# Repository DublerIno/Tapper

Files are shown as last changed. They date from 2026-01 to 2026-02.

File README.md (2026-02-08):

# Tapper
Simple BPM counter and metronome on custom board, replacing apps filled with Ads. 
STM32G030F6P6 TSSOP20 as a brain. MX Cherry switch for satisfying click. OLED for visuals. 

## GOAL
This simple project may seem like reinventing the wheel, but my main goal is to learn:
- STM32 Programming pipeline
- Custom PCB design for embedded systems
- Microsoldering 

### STM32G030F6P6 Dev Board
Currently, I am working on my custom development board to test the following features:
- STlink connection
- USBC connection with CH340E for UART
- Battery charging circuit for LiPo with MCP73831
- OLED test circuit
- STM32 pinouts

### Current status
- PCB done
- Soldering done
- Circuit testing successful
- Now programming..
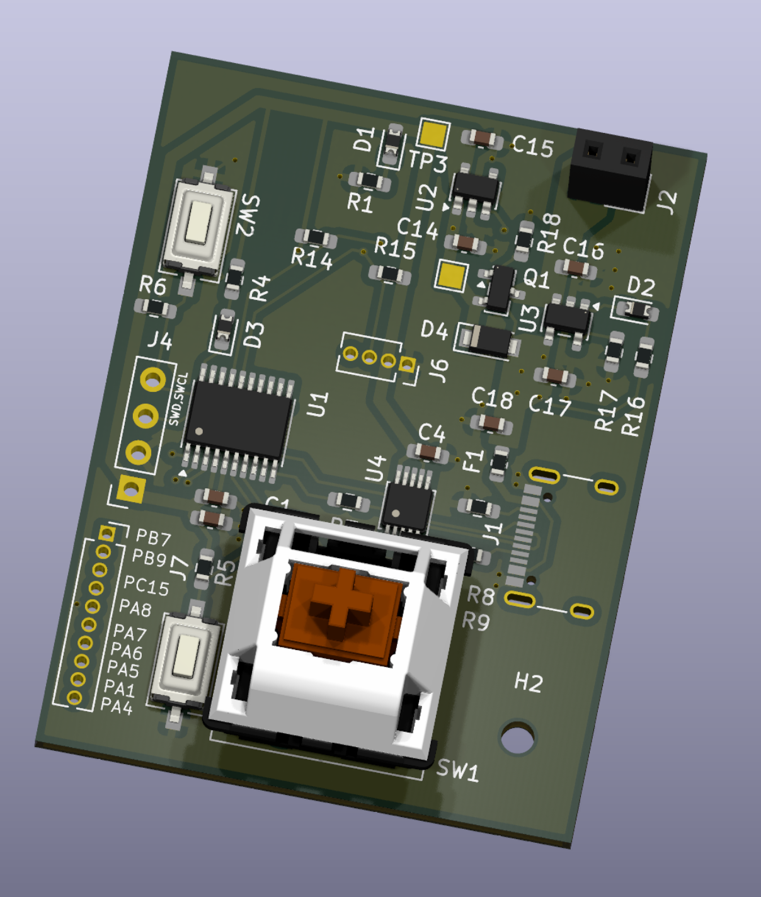
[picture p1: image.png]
Tapper Dev board v1


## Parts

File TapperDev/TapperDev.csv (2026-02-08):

Reference | Qty | Value | DNP | Exclude from BOM | Exclude from Board | Footprint | Datasheet
C1 | 1 | 10u |  |  |  | Capacitor_SMD:C_0603_1608Metric_Pad1.08x0.95mm_HandSolder | ~
C2,C4,C18 | 3 | 100n |  |  |  | Capacitor_SMD:C_0603_1608Metric_Pad1.08x0.95mm_HandSolder | ~
C3,C5 | 2 | ?? | DNP |  | Vyloučit z desky | Capacitor_SMD:C_0603_1608Metric_Pad1.08x0.95mm_HandSolder | ~
C6 | 1 | 1uF/16v |  |  |  | Capacitor_SMD:C_0603_1608Metric_Pad1.08x0.95mm_HandSolder | ~
C7 | 1 | 1uF/16V |  |  |  | Capacitor_SMD:C_0603_1608Metric_Pad1.08x0.95mm_HandSolder | ~
C8,C10 | 2 | 4.7uF |  |  |  | Capacitor_SMD:C_0603_1608Metric_Pad1.08x0.95mm_HandSolder | ~
C9 | 1 | 0.1uF |  |  |  | Capacitor_SMD:C_0603_1608Metric_Pad1.08x0.95mm_HandSolder | ~
C11,C16,C17 | 3 | 4.7uF/16V |  |  |  | Capacitor_SMD:C_0603_1608Metric_Pad1.08x0.95mm_HandSolder | ~
C12 | 1 | 0.1uF/16V |  |  |  | Capacitor_SMD:C_0603_1608Metric_Pad1.08x0.95mm_HandSolder | ~
C13 | 1 | 2.2uF/16V |  |  |  | Capacitor_SMD:C_0603_1608Metric_Pad1.08x0.95mm_HandSolder | ~
C14,C15 | 2 | 1uF |  |  |  | Capacitor_SMD:C_0603_1608Metric_Pad1.08x0.95mm_HandSolder | ~
D1 | 1 | LED green |  |  |  | Diode_SMD:D_0603_1608Metric_Pad1.05x0.95mm_HandSolder | ~
D2,D3 | 2 | LED red |  |  |  | Diode_SMD:D_0603_1608Metric_Pad1.05x0.95mm_HandSolder | ~
D4 | 1 | 500mA 30V |  |  |  | Diode_SMD:Nexperia_CFP3_SOD-123W | https://www.diodes.com/assets/Datasheets/ds30396.pdf
F1 | 1 | 6v 500mA |  |  |  | Diode_SMD:Nexperia_CFP3_SOD-123W | ~
J1 | 1 | USB_C_Receptacle_USB2.0_16P |  |  |  | Connector_USB:USB_C_Receptacle_XKB_U262-16XN-4BVC11 | https://www.usb.org/sites/default/files/documents/usb_type-c.zip
J2 | 1 | Conn_01x02 |  |  |  | Connector_PinSocket_2.54mm:PinSocket_1x02_P2.54mm_Vertical | ~
J3 | 1 | Conn_01x14 |  |  |  | Connector_FFC-FPC:TE_1-84952-4_1x14-1MP_P1.0mm_Horizontal | ~
J4 | 1 | Conn_01x04 |  |  |  | Connector_PinSocket_2.54mm:PinSocket_1x04_P2.54mm_Vertical | ~
J6 | 1 | Conn_01x04 |  |  |  | Connector_PinSocket_1.27mm:PinSocket_1x04_P1.27mm_Vertical | ~
J7 | 1 | Conn_01x10_Pin |  |  |  | Connector_PinSocket_1.27mm:PinSocket_1x10_P1.27mm_Vertical | ~
Q1 | 1 | PMOS ?? |  |  |  | Package_TO_SOT_SMD:SOT-23 | https://ngspice.sourceforge.io/docs/ngspice-html-manual/manual.xhtml#cha_MOSFETs
R1,R4,R7 | 3 | 1k |  |  |  | Resistor_SMD:R_0603_1608Metric_Pad0.98x0.95mm_HandSolder | ~
R5,R6 | 2 | 10k |  |  |  | Resistor_SMD:R_0603_1608Metric_Pad0.98x0.95mm_HandSolder | ~
R8,R9,R14,R15,R17 | 5 | 5k1 |  |  |  | Resistor_SMD:R_0603_1608Metric_Pad0.98x0.95mm_HandSolder | ~
R12 | 1 | 4k7 |  |  |  | Resistor_SMD:R_0603_1608Metric_Pad0.98x0.95mm_HandSolder | ~
R13 | 1 | 560k |  |  |  | Resistor_SMD:R_0603_1608Metric_Pad0.98x0.95mm_HandSolder | ~
R16 | 1 | ! for 5V |  |  |  | Resistor_SMD:R_0603_1608Metric_Pad0.98x0.95mm_HandSolder | ~
R18 | 1 | 100k |  |  |  | Resistor_SMD:R_0603_1608Metric_Pad0.98x0.95mm_HandSolder | ~
SW1 | 1 | SW_Push |  |  |  | PCM_Switch_Keyboard_Cherry_MX:SW_Cherry_MX_PCB | ~
SW2,SW3 | 2 | SW_Push |  |  |  | Button_Switch_SMD:SW_Tactile_SPST_NO_Straight_CK_PTS636Sx25SMTRLFS | ~
TP1,TP2,TP3,TP4,TP5 | 5 | TestPoint |  |  |  | TestPoint:TestPoint_Pad_1.5x1.5mm | ~
U1 | 1 | STM32G030F6Px |  |  |  | Package_SO:TSSOP-20_4.4x6.5mm_P0.65mm | https://www.st.com/resource/en/datasheet/stm32g030f6.pdf
U2 | 1 | TLV75533PDBV |  |  |  | Package_TO_SOT_SMD:SOT-23-5 | http://www.ti.com/lit/ds/symlink/tlv755p.pdf
U3 | 1 | MCP73811T-420I-OT |  |  |  | Package_TO_SOT_SMD:SOT-23-5 | http://ww1.microchip.com/downloads/en/DeviceDoc/22036b.pdf
U4 | 1 | CH340E |  |  |  | Package_SO:MSOP-10_3x3mm_P0.5mm | https://www.mpja.com/download/35227cpdata.pdf
Y1 | 1 | Crystal 16Mhz 20pF | DNP |  | Vyloučit z desky | Crystal:Crystal_HC49-U_Vertical | ~

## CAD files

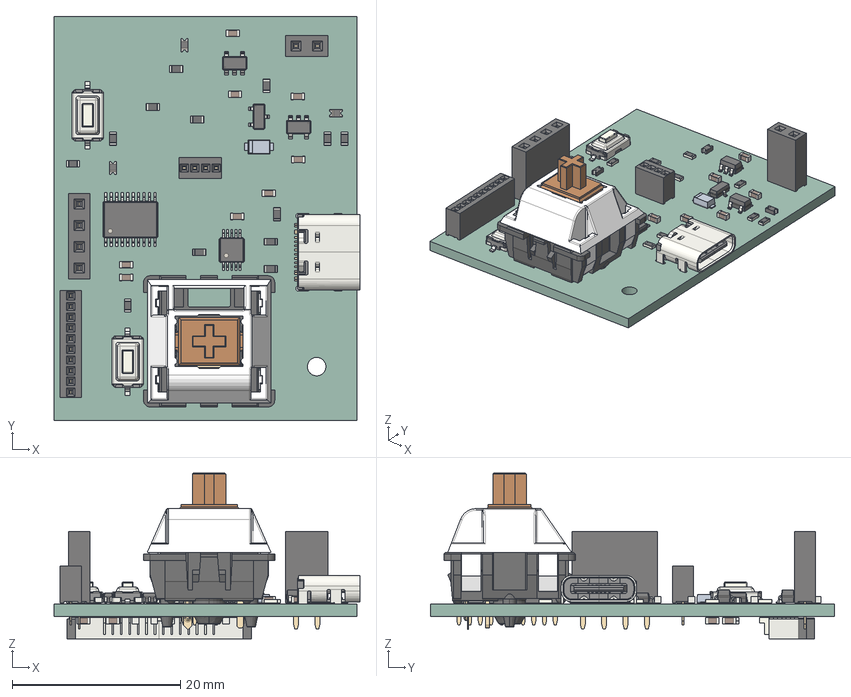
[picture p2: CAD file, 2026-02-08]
TapperDev/TapperDev.step
36.3 x 48.0 x 19.7 mm
R_0603_1608Metric x 14
SW_Cherry_MX_PCB
USB_C_Receptacle_GCT_USB4105-xx-A_16P_TopMnt_Horizontal
Fuse_0603_1608Metric
PinSocket_1x04_P2.54mm_Vertical
D_0603_1608Metric x 3
C_0603_1608Metric x 16
PinSocket_1x04_P1.27mm_Vertical
SOT-23-5 x 2
SW_Tactile_SPST_NO_Straight_CK_PTS636Sx25SMTRLFS x 2
TSSOP-20_4.4x6.5mm_P0.65mm
PinSocket_1x10_P1.27mm_Vertical
PinSocket_1x02_P2.54mm_Vertical
MSOP-10_3x3mm_P0.5mm
SOT-23
TapperDev 1.38.1
TE_1-84952-4_1x14-1MP_P1.0mm_Horizontal
TapperDev_PCB

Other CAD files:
TapperDev/TapperDev.stl
TapperDev/TapperS.f3d

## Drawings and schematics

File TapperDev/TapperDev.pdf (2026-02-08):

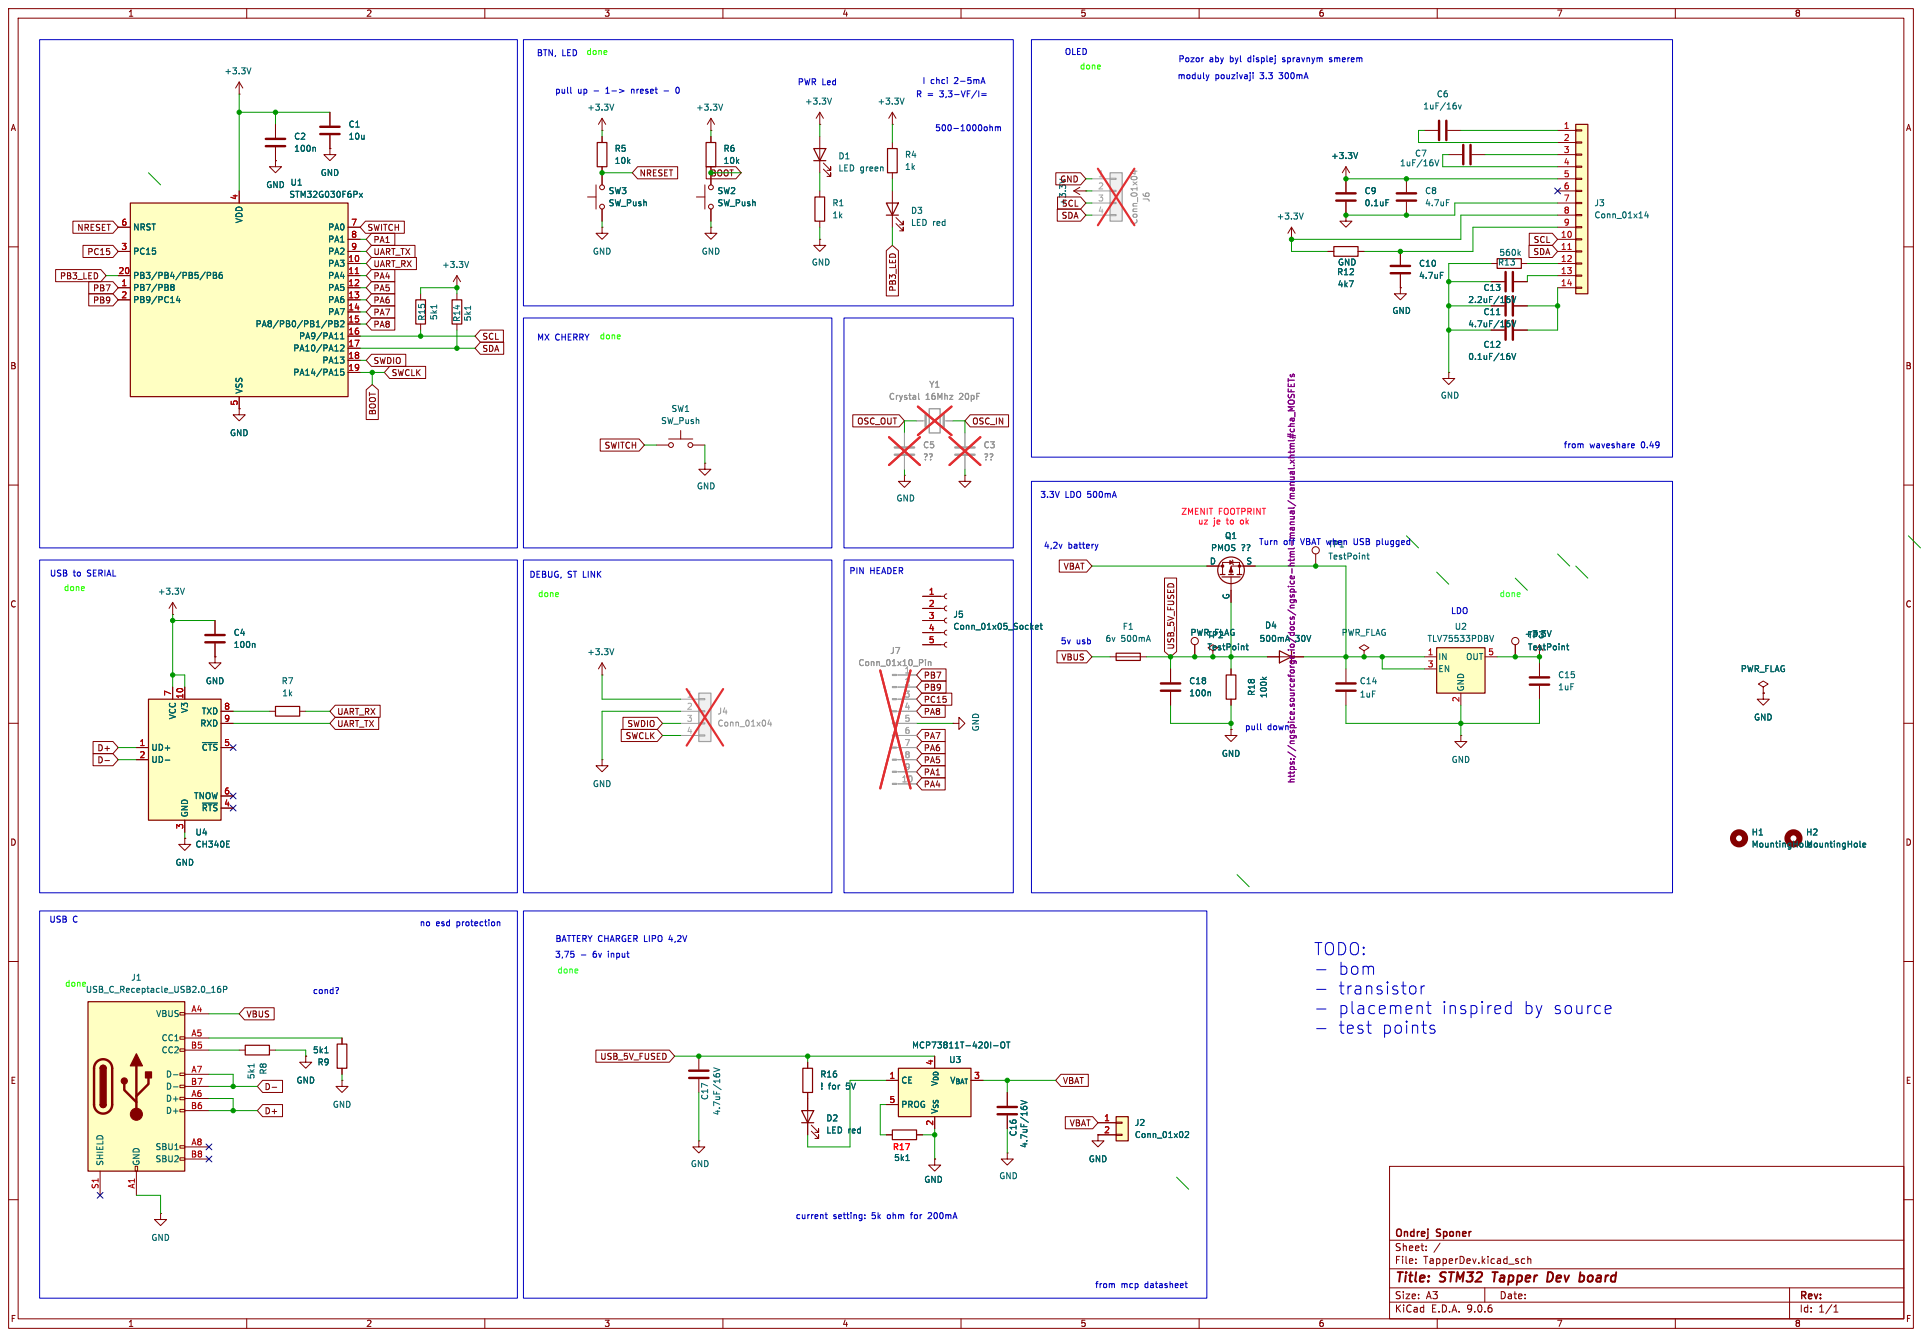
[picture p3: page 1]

Pozor aby byl displej spravnym smerem

done DEBUG, ST LINK
PIN HEADER MX CHERRY

from waveshare 0.49 Turn off VBAT when USB plugged BATTERY CHARGER LIPO 4,2V

3 TXD 8 RXD 9 ~{CTS}5 TNOW 6 ~{RTS}4 GND

3 TXD 8 RXD 9 ~{CTS}5 TNOW 6 ~{RTS}4 U4 CH340E

File: TapperDev.kicad_sch Sheet: / Ondrej Sponer

Id: 1/1 Title: STM32 Tapper Dev board

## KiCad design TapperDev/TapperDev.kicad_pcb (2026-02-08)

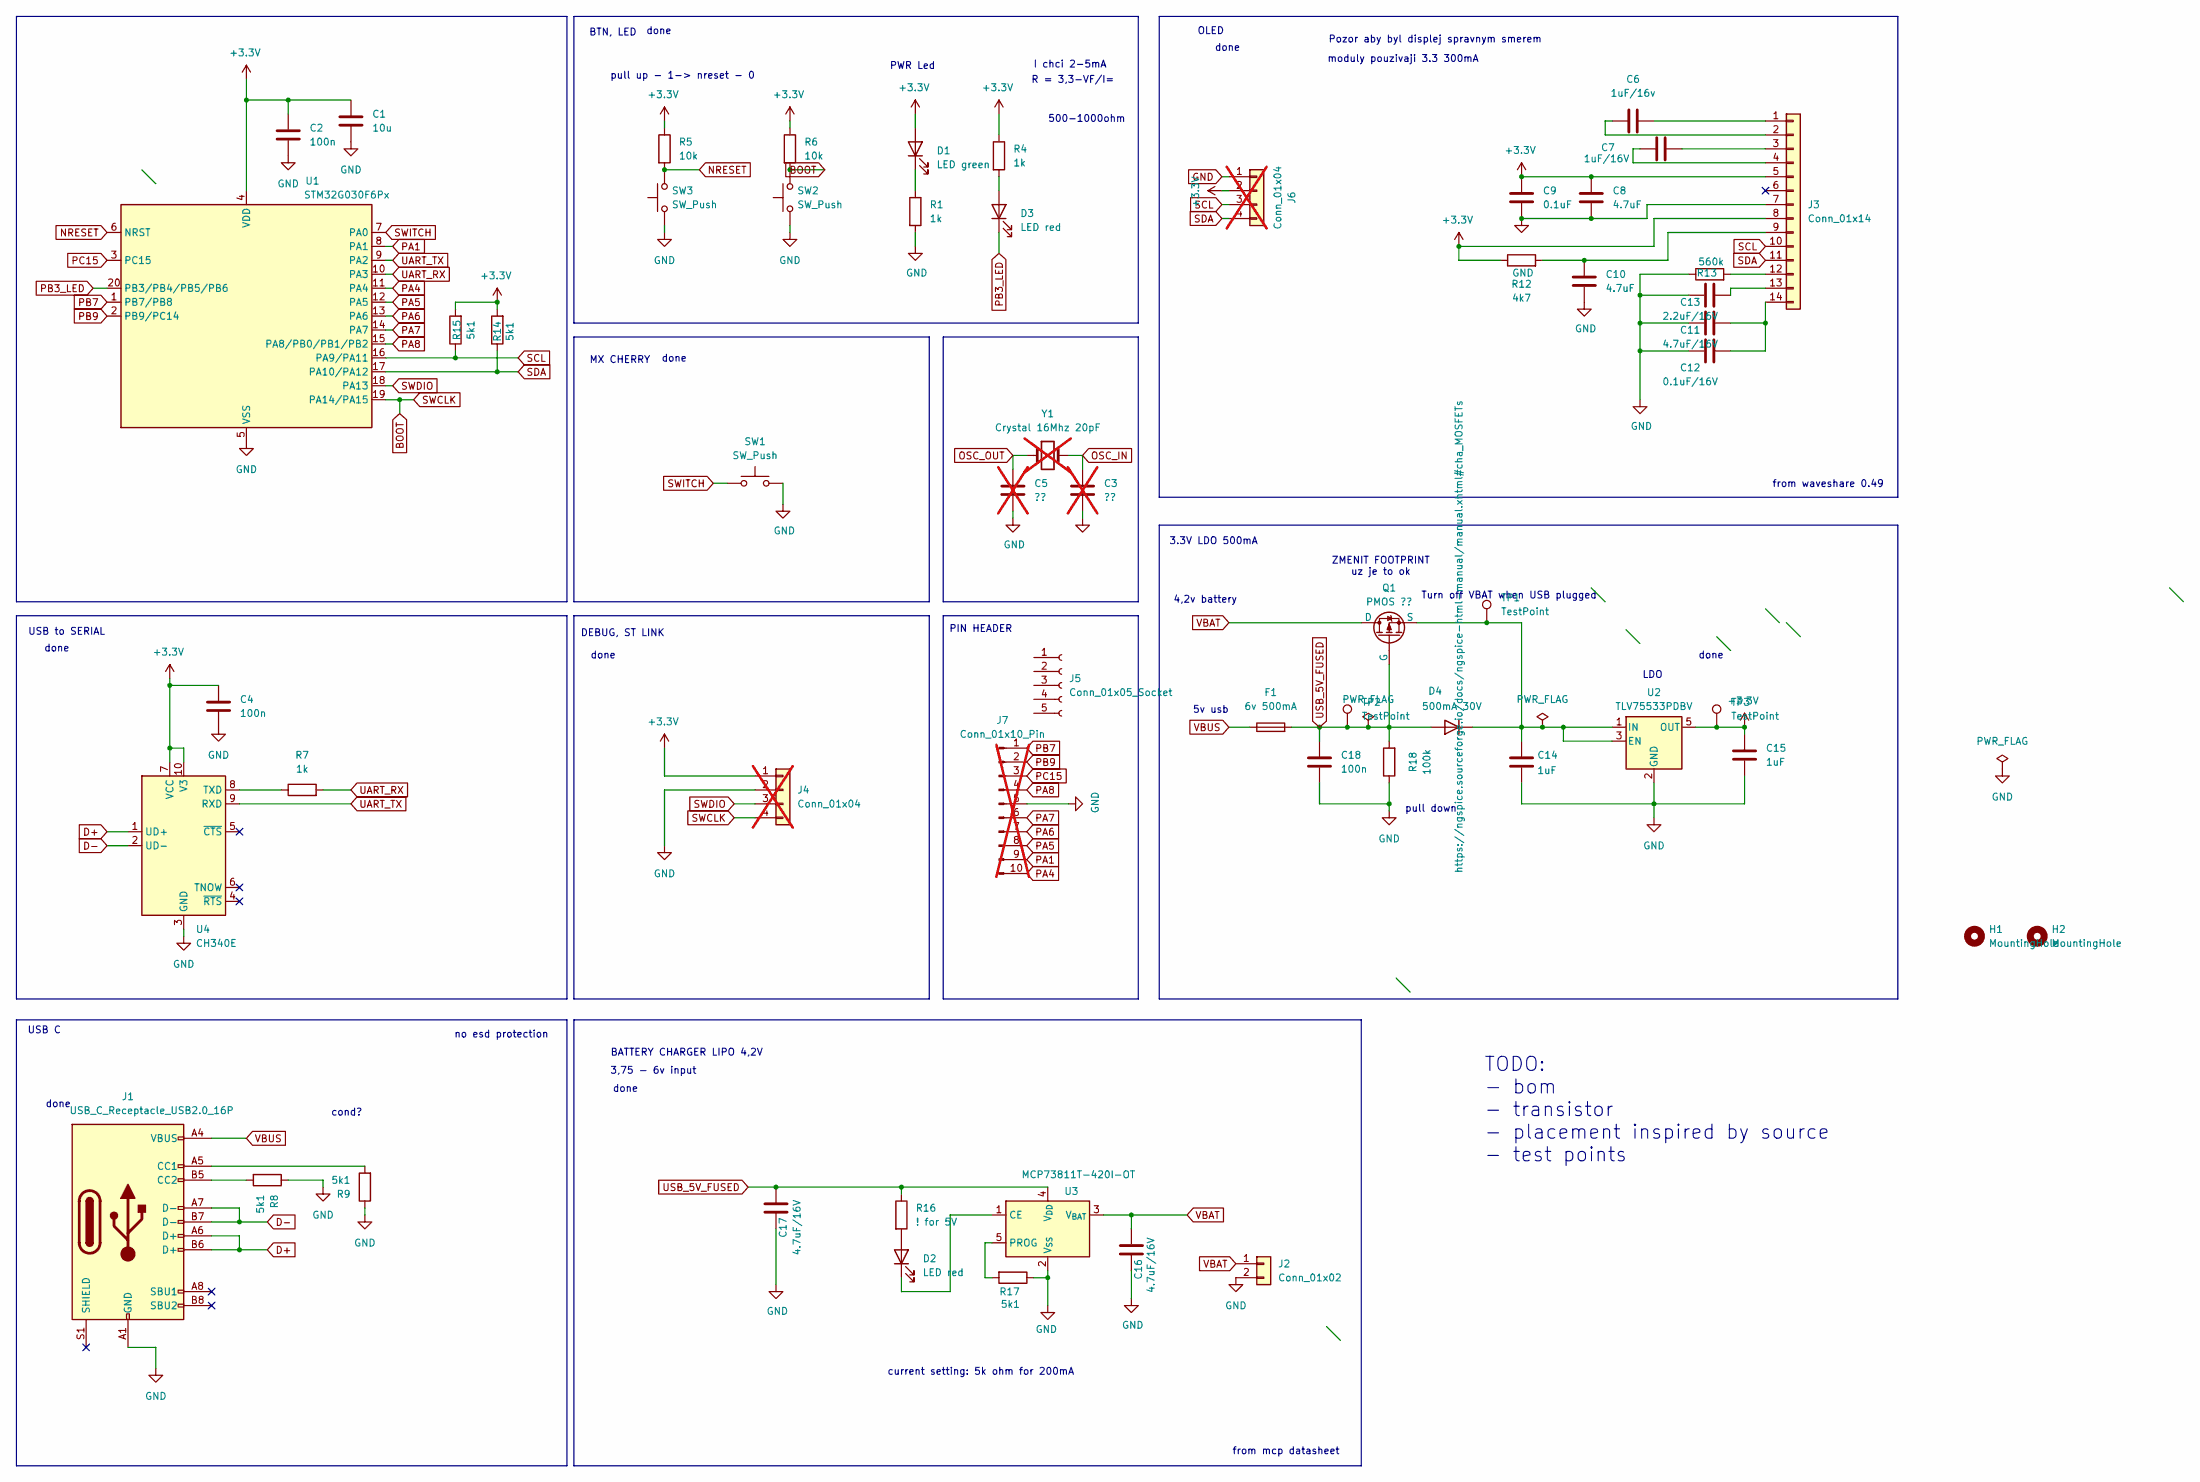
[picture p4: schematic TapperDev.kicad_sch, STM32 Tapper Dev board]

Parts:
C1: 10u; C_0603_1608Metric_Pad1.08x0.95mm_HandSolder
C2, C4, C18: 100n; C_0603_1608Metric_Pad1.08x0.95mm_HandSolder
C3, C5: ??; C_0603_1608Metric_Pad1.08x0.95mm_HandSolder; not fitted
C6: 1uF/16v; C_0603_1608Metric_Pad1.08x0.95mm_HandSolder
C7: 1uF/16V; C_0603_1608Metric_Pad1.08x0.95mm_HandSolder
C8, C10: 4.7uF; C_0603_1608Metric_Pad1.08x0.95mm_HandSolder
C9: 0.1uF; C_0603_1608Metric_Pad1.08x0.95mm_HandSolder
C11, C16, C17: 4.7uF/16V; C_0603_1608Metric_Pad1.08x0.95mm_HandSolder
C12: 0.1uF/16V; C_0603_1608Metric_Pad1.08x0.95mm_HandSolder
C13: 2.2uF/16V; C_0603_1608Metric_Pad1.08x0.95mm_HandSolder
C14, C15: 1uF; C_0603_1608Metric_Pad1.08x0.95mm_HandSolder
D1: LED green; D_0603_1608Metric_Pad1.05x0.95mm_HandSolder
D2, D3: LED red; D_0603_1608Metric_Pad1.05x0.95mm_HandSolder
D4: 500mA 30V; Nexperia_CFP3_SOD-123W
F1: 6v 500mA; Fuse_0603_1608Metric
H1, H2: MountingHole; MountingHole_2.2mm_M2
J1: USB_C_Receptacle_USB2.0_16P; USB_C_Receptacle_XKB_U262-16XN-4BVC11
J2: Conn_01x02; PinSocket_1x02_P2.54mm_Vertical
J3: Conn_01x14; TE_1-84952-4_1x14-1MP_P1.0mm_Horizontal
J4: Conn_01x04; PinSocket_1x04_P2.54mm_Vertical; not fitted
J5: Conn_01x05_Socket
J6: Conn_01x04; PinSocket_1x04_P1.27mm_Vertical; not fitted
J7: Conn_01x10_Pin; PinSocket_1x10_P1.27mm_Vertical; not fitted
Q1: PMOS ??; SOT-23
R1, R4, R7: 1k; R_0603_1608Metric_Pad0.98x0.95mm_HandSolder
R5, R6: 10k; R_0603_1608Metric_Pad0.98x0.95mm_HandSolder
R8, R9, R14, R15, R17: 5k1; R_0603_1608Metric_Pad0.98x0.95mm_HandSolder
R12: 4k7; R_0603_1608Metric_Pad0.98x0.95mm_HandSolder
R13: 560k; R_0603_1608Metric_Pad0.98x0.95mm_HandSolder
R16: ! for 5V; R_0603_1608Metric_Pad0.98x0.95mm_HandSolder
R18: 100k; R_0603_1608Metric_Pad0.98x0.95mm_HandSolder
SW1: SW_Push; SW_Cherry_MX_PCB
SW2, SW3: SW_Push; SW_Tactile_SPST_NO_Straight_CK_PTS636Sx25SMTRLFS
TP1, TP2, TP3: TestPoint; TestPoint_Pad_1.5x1.5mm
U1: STM32G030F6Px; TSSOP-20_4.4x6.5mm_P0.65mm
U2: TLV75533PDBV; SOT-23-5
U3: MCP73811T-420I-OT; SOT-23-5
U4: CH340E; MSOP-10_3x3mm_P0.5mm
Y1: Crystal 16Mhz 20pF; Crystal_HC49-U_Vertical; not fitted

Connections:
+3.3V: C1.1, C2.1, C4.1, C8.1, C9.1, C15.1, D1.2 (A), J3.5, J3.8, J4.1, J6.2, R4.1, R5.1, R6.1, R12.1, R14.2, R15.2, TP3.1, U1.4 (VDD), U2.5 (OUT), U4.7 (VCC), U4.10 (V3)
BOOT: J4.4, R6.2, SW2.2, U1.19 (PA14/PA15)
D+: J1.A6 (D+), J1.B6 (D+), U4.1 (UD+)
D-: J1.A7 (D-), J1.B7 (D-), U4.2 (UD-)
GND: C1.2, C2.2, C3.2, C4.2, C5.2, C8.2, C9.2, C10.2, C11.2, C12.1, C13.2, C14.2, C15.2, C16.2, C17.2, C18.2, J1.A1 (GND), J1.A12 (GND), J1.B1 (GND), J1.B12 (GND), J2.2, J3.7, J4.2, J6.1, J7.5, R1.2, R8.1, R9.1, R13.1, R17.1, R18.1, SW1.2, SW2.1, SW3.1, U1.5 (VSS), U2.2 (GND), U3.2 (V_{SS}), U4.3 (GND)
NRESET: R5.2, SW3.2, U1.6 (NRST)
unnamed: C3.1, Y1.2
unnamed: C5.1, Y1.1
unnamed: D1.1 (K), R1.1
unnamed: D2.2 (A), R16.2
unnamed: D2.1 (K), U3.1 (CE)
unnamed: D3.2 (A), R4.2
unnamed: C14.1, D4.1 (K), Q1.2 (S), TP1.1, U2.1 (IN), U2.3 (EN)
unnamed: J1.A5 (CC1), R9.2
unnamed: J1.B5 (CC2), R8.2
unnamed: C6.2, J3.1
unnamed: C6.1, J3.2
unnamed: C7.2, J3.3
unnamed: C7.1, J3.4
unnamed: C10.1, J3.9, R12.2
unnamed: J3.12, R13.2
unnamed: C13.1, J3.13
unnamed: C11.1, C12.2, J3.14
unnamed: R17.2, U3.5 (PROG)
unnamed: R7.1, U4.8 (TXD)
PA1: J7.9, U1.8 (PA1)
PA4: J7.10, U1.11 (PA4)
PA5: J7.8, U1.12 (PA5)
PA6: J7.7, U1.13 (PA6)
PA7: J7.6, U1.14 (PA7)
PA8: J7.4, U1.15 (PA8/PB0/PB1/PB2)
PB3_LED: D3.1 (K), U1.20 (PB3/PB4/PB5/PB6)
PB7: J7.1, U1.1 (PB7/PB8)
PB9: J7.2, U1.2 (PB9/PC14)
PC15: J7.3, U1.3 (PC15)
SCL: J3.10, J6.3, R15.1, U1.16 (PA9/PA11)
SDA: J3.11, J6.4, R14.1, U1.17 (PA10/PA12)
SWDIO: J4.3, U1.18 (PA13)
SWITCH: SW1.1, U1.7 (PA0)
UART_RX: R7.2, U1.10 (PA3)
UART_TX: U1.9 (PA2), U4.9 (RXD)
USB_5V_FUSED: C17.1, C18.1, D4.2 (A), F1.2, Q1.1 (G), R16.1, R18.2, TP2.1, U3.4 (V_{DD})
VBAT: C16.1, J2.1, Q1.3 (D), U3.3 (V_{BAT})
VBUS: F1.1, J1.A4 (VBUS), J1.A9 (VBUS), J1.B4 (VBUS), J1.B9 (VBUS)

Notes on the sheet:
ZMENIT FOOTPRINT uz je to ok
from waveshare 0.49
done
4,2v battery
500-1000ohm
no esd protection
from mcp datasheet
USB to SERIAL
PIN HEADER
USB C
MX CHERRY
I chci 2-5mA
BTN, LED
PWR Led
pull down
DEBUG, ST LINK
5v usb
cond?
OLED
3,75 - 6v input
current setting: 5k ohm for 200mA
BATTERY CHARGER LIPO 4,2V
Pozor aby byl displej spravnym smerem
LDO
TODO: - bom - transistor - placement inspired by source - test points
R = 3,3-VF/I=
pull up - 1-> nreset - 0
Turn off VBAT when USB plugged
3.3V LDO 500mA
moduly pouzivaji 3.3 300mA

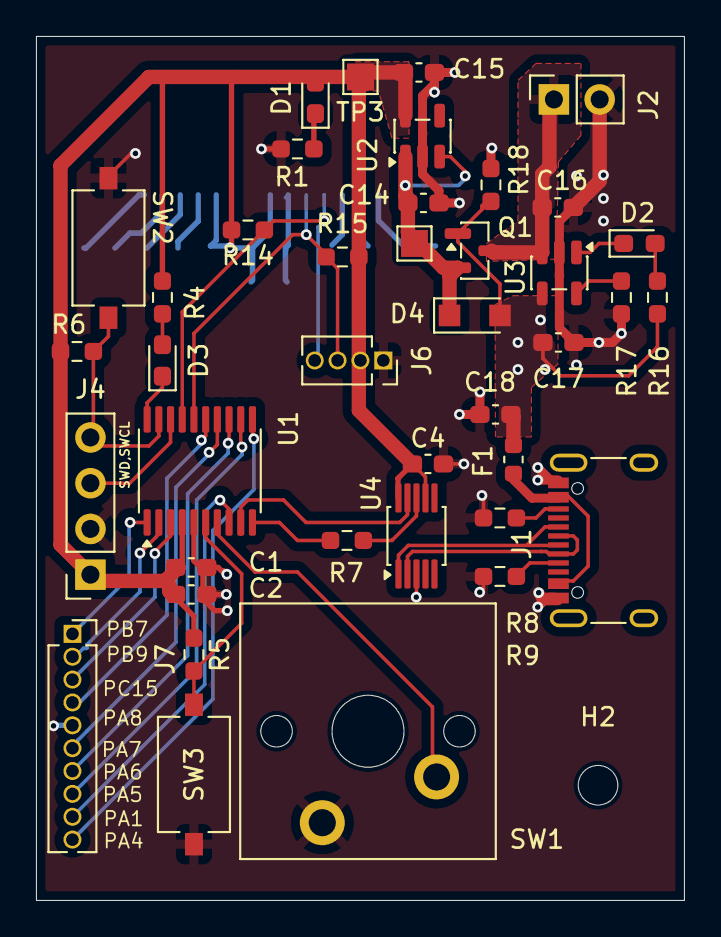
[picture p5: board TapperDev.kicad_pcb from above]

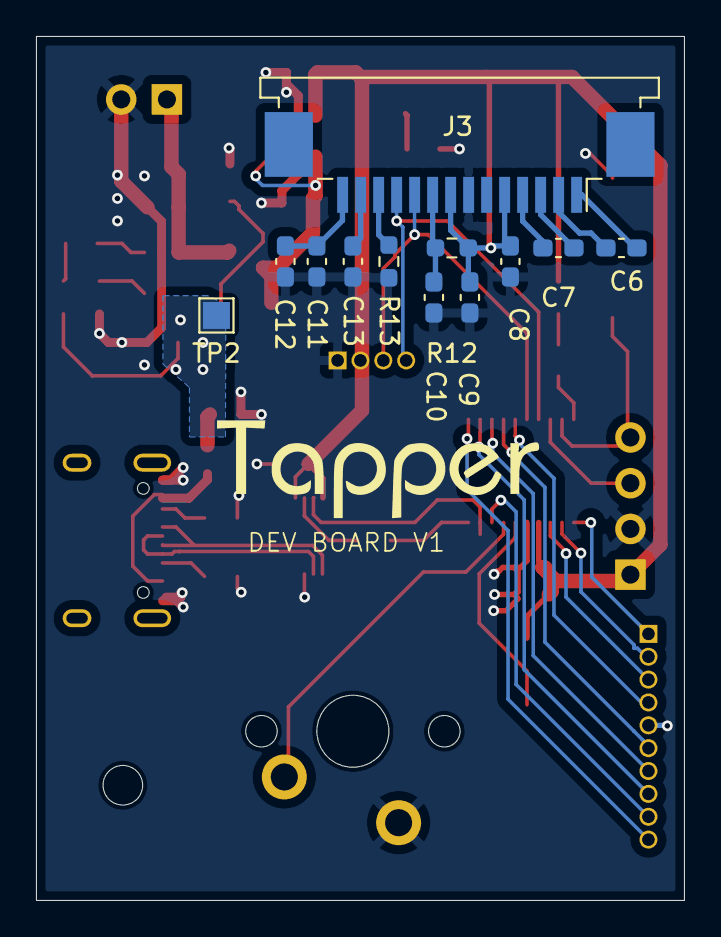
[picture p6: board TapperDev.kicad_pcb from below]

Board: 2 copper layers, 36.0 x 48.0 mm, 53 parts (12 on the bottom side), 42 nets.

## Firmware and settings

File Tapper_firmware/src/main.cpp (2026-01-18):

// Basic BPM (Beats Per Minute) Calculator for ESP32
#include <Arduino.h>
#include "display.h"


const int buttonPin = 0;

unsigned long clickTimes[4];
int clickCount = 0;
bool previousState = HIGH;

void setup() {
  pinMode(buttonPin, INPUT_PULLUP);
  Serial.begin(115200);
  Display::display_init();
}

void loop() {
  bool currentState = digitalRead(buttonPin);

  // Detect button press (falling edge)
  if (previousState == HIGH && currentState == LOW) {
    if (clickCount < 4) {
      clickTimes[clickCount] = millis();
      clickCount++;
    }

    if (clickCount == 4) {
      unsigned long interval = clickTimes[3] - clickTimes[0]; // ms between 1st and 4th clicks
      float seconds = interval / 1000.0;
      float beats = 3.0;  // 4 clicks → 3 intervals
      float bpm = (beats / seconds) * 60.0;

      Serial.print("BPM: ");
      Serial.println(bpm);
      Display::display_show_bpm(bpm);


      clickCount = 0; // reset for next measurement
    }
  }

  previousState = currentState;
} 

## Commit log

2026-01-18 Fix image link in README.md
    Updated image link in README for the first dev board.
2026-02-08 Revise STM32G030F6P6 Dev Board features and image
    Updated the features list for the STM32G030F6P6 Dev Board and improved the image caption.
2026-02-08 added kicad project files
    [TapperDev-B_Cu.gbr, TapperDev-B_Mask.gbr, TapperDev-B_Paste.gbr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]
2026-02-08 Update README with current project status
    Added current status of the development board project.
